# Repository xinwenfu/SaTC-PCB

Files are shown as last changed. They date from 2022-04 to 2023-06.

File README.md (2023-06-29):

# SIC2_EDU

## Version 1
Programming &amp; Hardware guide for SIC2_EDU security IoT kit 

SatC_EDU project is an ESP32 based board designed to communicate with AWS or other data servers, in this case using MQTT more securely. On-board is an ATECC608 Crypto authentication chip that provides a means for IoT to communcate more securely.

SatC_EDU Board in bumper case render ~ (Autodesk, Fusion360)
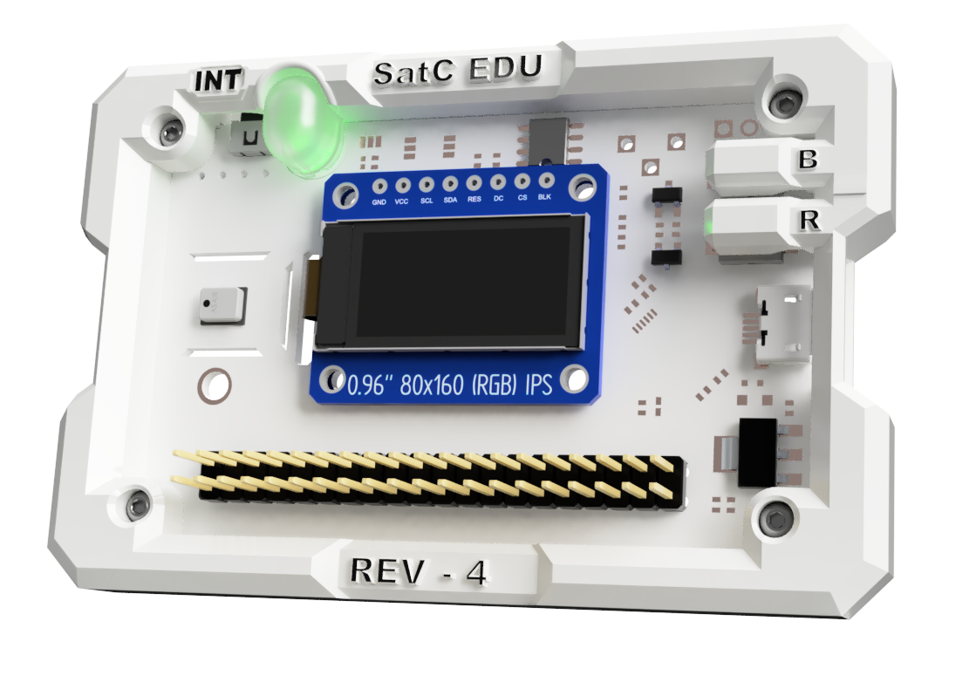
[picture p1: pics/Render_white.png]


Schematic ~ (Based on schems from espressif)
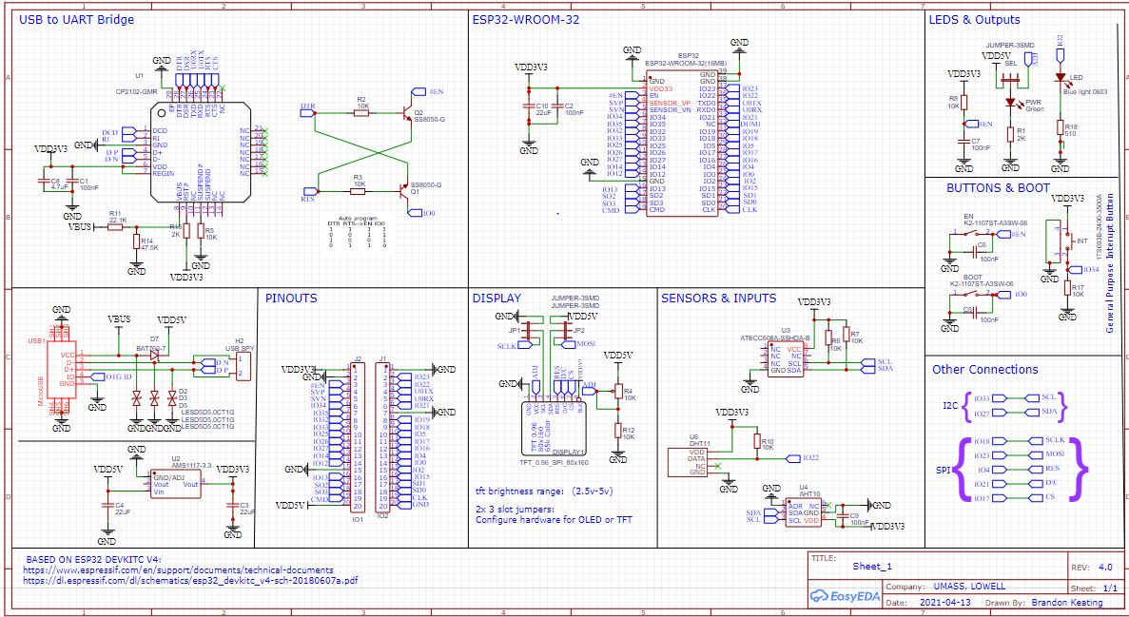
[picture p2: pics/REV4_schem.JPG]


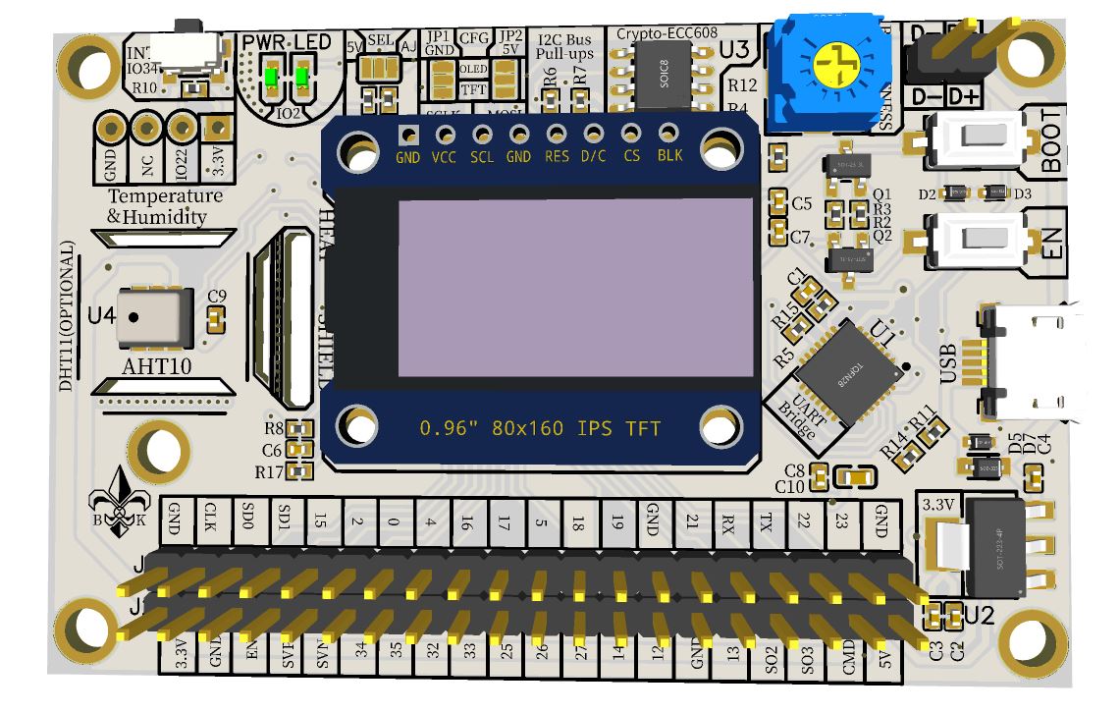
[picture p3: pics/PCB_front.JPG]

Front Face of PCB

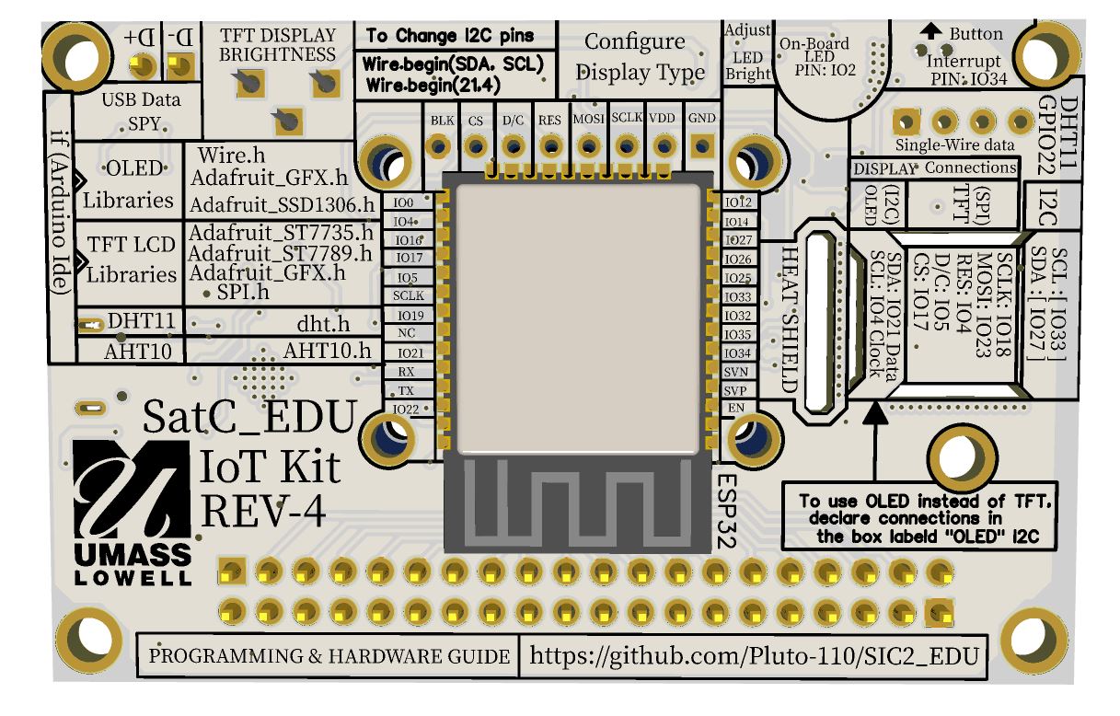
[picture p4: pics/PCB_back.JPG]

Back Face of PCB

## Version 2
Version 2 of the PCB is available at [Amazon](https://www.amazon.com/dp/B0C24FJBG9)
Security chip model: HSC32I1NBV60X2115, compatible with ECC608

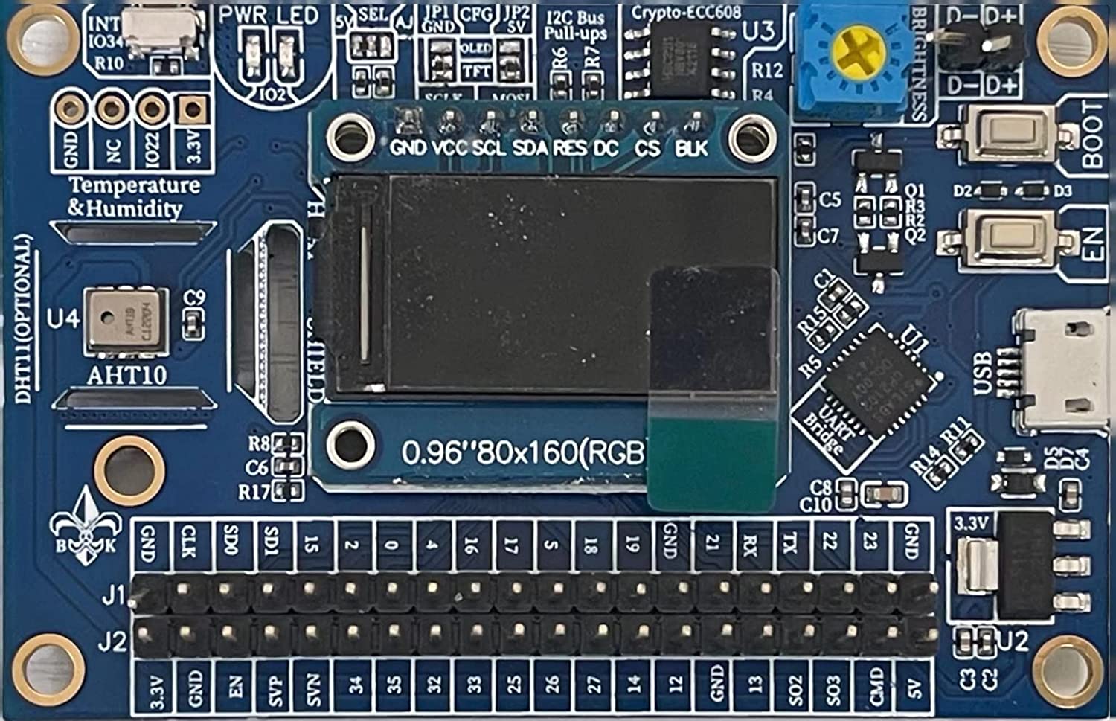
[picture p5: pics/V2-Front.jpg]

Front Face of PCB

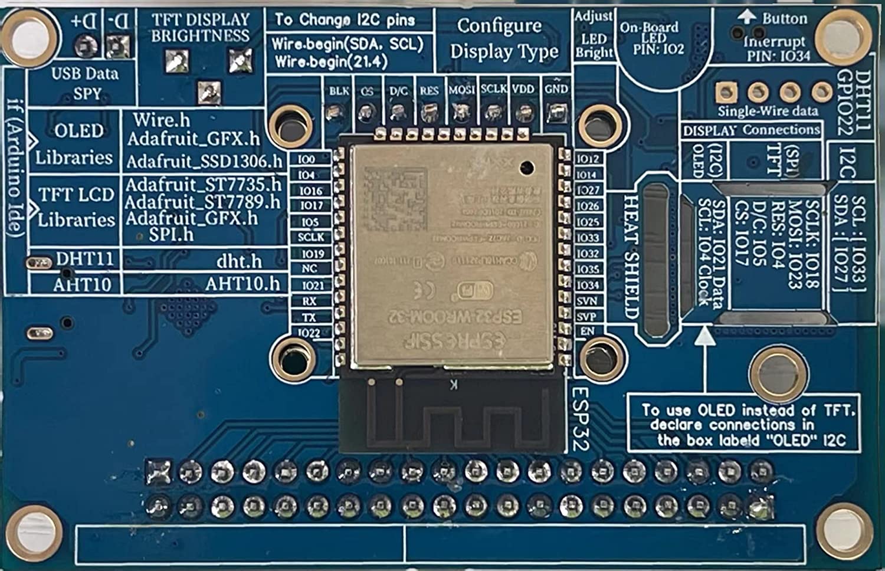
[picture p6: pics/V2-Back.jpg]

Back Face of PCB

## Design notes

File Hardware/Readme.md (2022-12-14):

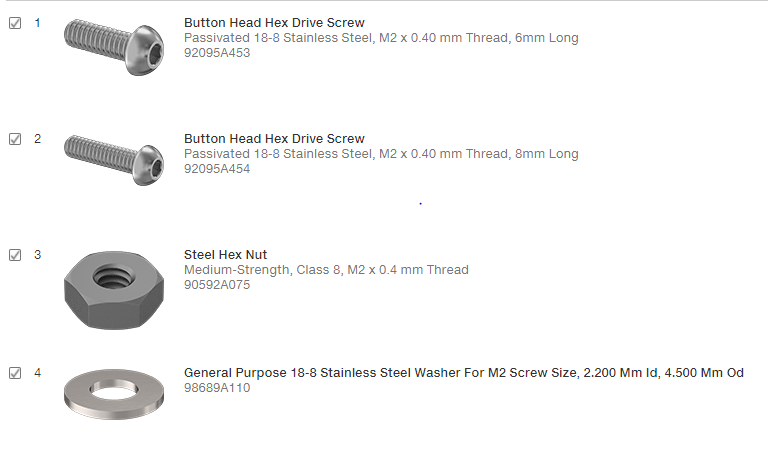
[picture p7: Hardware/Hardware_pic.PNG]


  Per Unit: [Full Hareware]
    4x M2 Hex Drive 8mm Screw (4 corners of the case)
    5x M2 Hex Drive 6mm Screw (1x for DHT22, 4x for TFT screen)
    4x Steel Hex Nut
    12x M2 general purpose washer (Board to TFT screen seperators) 

  Per Unit: [Minimal Hareware]
    2x M2 Hex Drive 8mm Screw (2 opposite corners of the case)
    1x M2 Hex Drive 6mm Screw (1x for DHT22)
    4x Steel Hex Nut

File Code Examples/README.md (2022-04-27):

Our board works with Arduino. Set the board as ESP32 Dev Module.

Our board works with the ESP-IDF extension and PlatformIO extension of VSCode. 

For the PlatformIO extension, use the board Espressif ESP32 Dev Module. In the interface of PIO, we can use "Import Arduino Project" to import an Arduino project. There is no need marking "Use libraries installed by Arduino IDE".

platformio.ini looks like the following
```
; PlatformIO Project Configuration File
;
;   Build options: build flags, source filter
;   Upload options: custom upload port, speed and extra flags
;   Library options: dependencies, extra library storages
;   Advanced options: extra scripting
;
; Please visit documentation for the other options and examples
; https://docs.platformio.org/page/projectconf.html

[env:esp32dev]
platform = espressif32
board = esp32dev
framework = arduino
```

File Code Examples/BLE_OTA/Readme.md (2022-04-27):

This Example shows how  to use BLE to implement OTA for the SIC2_EDU board. This example is an adaptation of an existing guide to do OTA via BLE which can be found here below.

https://learn.sparkfun.com/tutorials/esp32-ota-updates-over-ble-from-a-react-web-application/all#introduction 

This is my board, not my code!! Code credit:  [ ENGLANDSAURUS ]

Tools needed:
  * SatC_EDU IoT Kit
  * A PC running Windows that has Arduino IDE installed (dont forget to add the espressif ESP32 board to the ide!) 
  * A PC running Linux (Ubunut, Arch, etc...), also have nodeJS and npm installed https://linuxize.com/post/how-to-install-node-js-on-ubuntu-20-04/
  * Micro-USB cable with data lines 

Setup:
  *add ESP32 capability to arduino ide : https://randomnerdtutorials.com/installing-the-esp32-board-in-arduino-ide-windows-instructions/
  *Install NPM and NODEJS to linux machine 
  
Step 1: (Arrange Files)
  Download or clone this repo and extract it to a known location. Do this on both the windows machine and the linux machine. 
  
Step 2: (Set up & Flash SatC_EDU)
  *Open arduino ide and open the Arduino sketch titled "BLE_OTA_main" 
  *Select the ESP32 Dev Module under "tools -> Board" in the ide
  *Under "Partitioon Schemes" select "Minimal SPIFFS(1.9MB APP with OTA/190KB SPIFFS", this will configure the partition sizes on the ESP32 to allocate space to store the update.
  
Step 3:
  *In the linux machine, open a command termnial (ctrl + alt + t) 
  *Navigate to where you unzipped the git clone and cd into WebApp
   if using the VM use " cd Desktop/ESP32_OTA_BLE_React_WebApp_Demo-master/WebApp " - NOTE:[ I extracted to the desktop but you can put the file anywhere... ]
  * Run the command "HPPT = true npm start". This will begin the WebApp

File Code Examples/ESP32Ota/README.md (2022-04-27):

This project is from https://github.com/atomic14/ESP32Ota.

# Introduction

This project demonstrates how to use the Arduino Over The Air update system on an ESP32.
Click the image to watch the demo video.

Demo Video (https://www.youtube.com/watch?v=_bMsrxiyuHs)

# Setup

Update the file `wifi_credentials.h` with your SSID and PASSWORD.

```c
#define SSID "YOUR_SSID"
#define PASSWORD "YOUR_PASSWORD"
```

Now just compile and run the sketch.

The first install will need to over USB.

Once the sketch is running you can go to "Tools" -> "Ports" and you should find your ESP32 listed as "esp_test".

You can change the name of your device by changing this line of code:

```c
ArduinoOTA.setHostname("esp_test");
```

# OTA in pio
In pio, we need to specify the upload_protocol and upload_port, which is the ip address of the board. One example platformio.ini looks like the following. This example uses the Arduino library installed by Arduino IDE. But really pay attention to the last two lines.

```
; PlatformIO Project Configuration File
;
;   Build options: build flags, source filter
;   Upload options: custom upload port, speed and extra flags
;   Library options: dependencies, extra library storages
;   Advanced options: extra scripting
;
; Please visit documentation for the other options and examples
; https://docs.platformio.org/page/projectconf.html

[env:esp32dev]
platform = espressif32
board = esp32dev
framework = arduino
lib_extra_dirs = ~/Documents/Arduino/libraries
monitor_speed = 115200

upload_protocol = espota
upload_port = 192.168.1.18
```

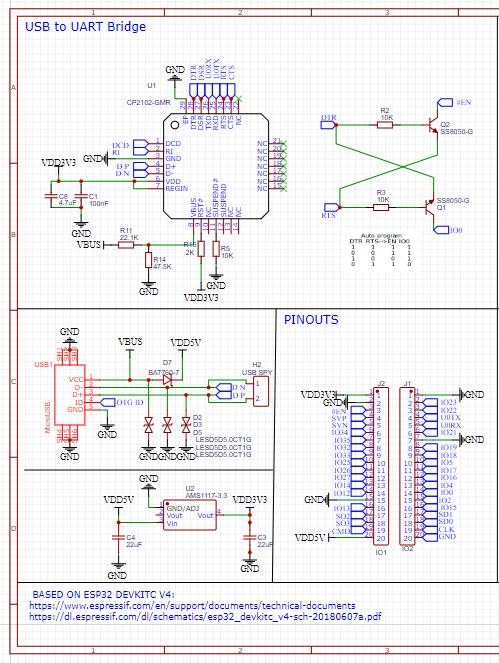
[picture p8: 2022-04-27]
pics/REV4_schem_cp2102.JPG

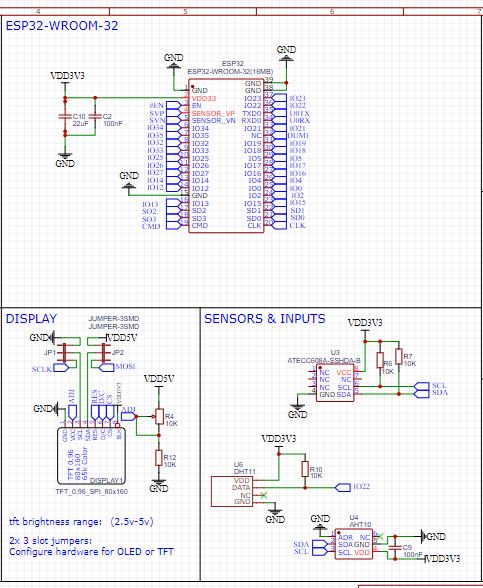
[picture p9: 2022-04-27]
pics/REV4_schem_esp32.JPG

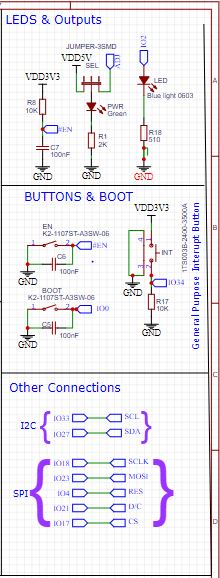
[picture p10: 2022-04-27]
pics/REV4_schem_cont.JPG

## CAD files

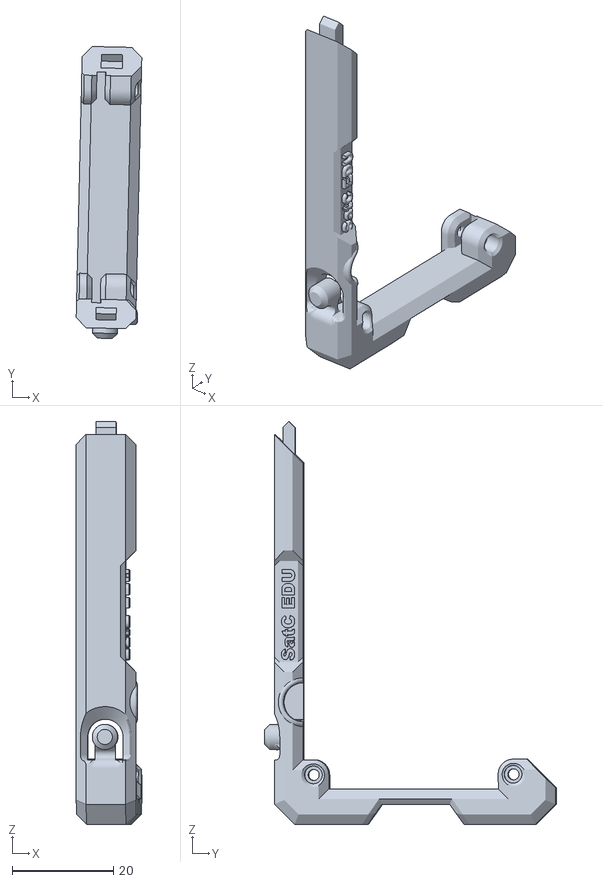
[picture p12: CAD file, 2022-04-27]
Case_stls/SIC2_case_full.stl
13.0 x 57.7 x 79.7

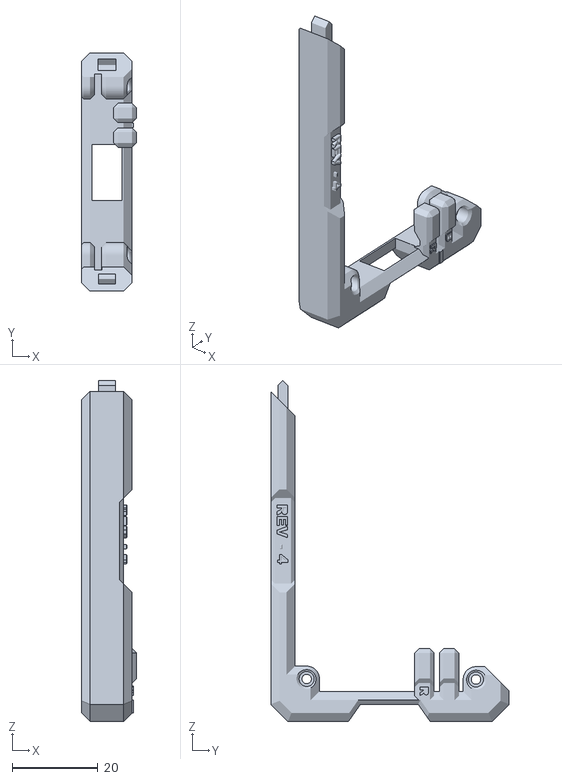
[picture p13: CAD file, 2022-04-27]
Case_stls/SIC2_case_buttons.stl
12.8 x 55.6 x 79.5

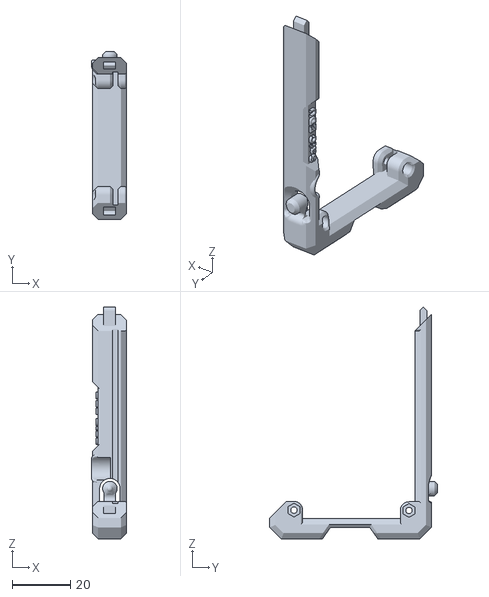
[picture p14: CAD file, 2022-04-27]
Case_stls/SIC2_case_LED_INT.stl
12.1 x 57.6 x 79.7

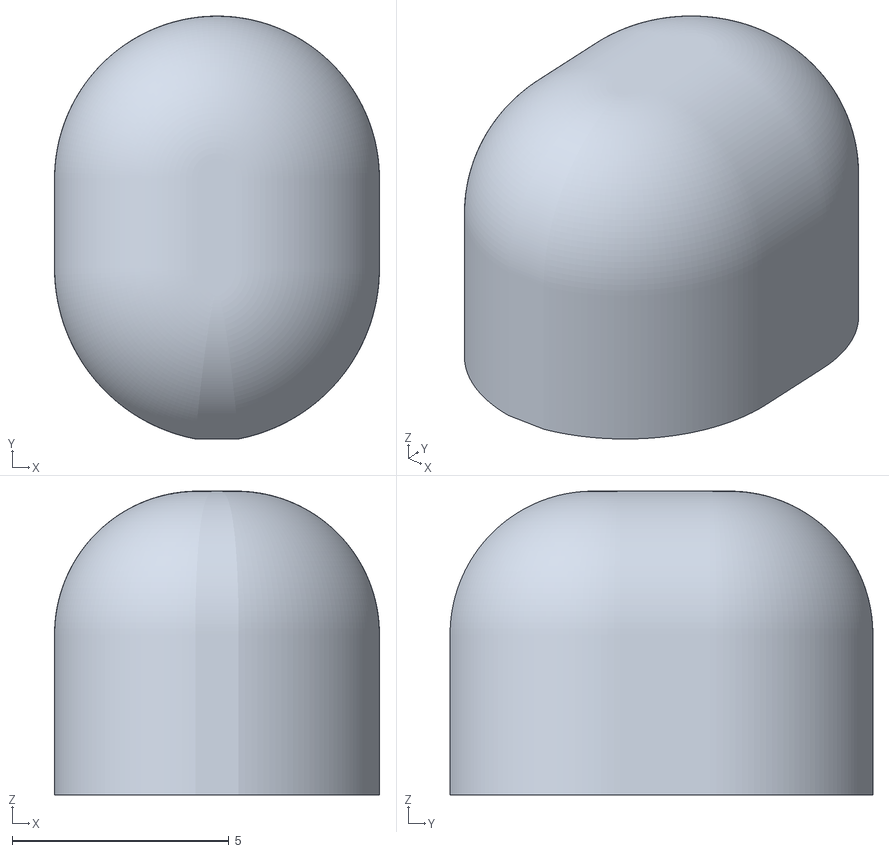
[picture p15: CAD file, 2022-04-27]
Case_stls/SIC2_case_Diffuser.stl
7.49 x 9.74 x 7.00

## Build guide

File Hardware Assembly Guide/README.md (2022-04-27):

# SIC2_EDU
## Assembly guide for SIC2_EDU security IoT kit Printed Circuit Board.

This is a guide on the assembly and soldering of the SatC_EDU IoT kit PCB.

The very first component that should be placed and soldered is the micro-USB connector that allows the board to be connected to a PC for programming and power. 

These connectors have two protrusions on the bottom that fit into the two board cut outs on the USB footprint outline. This makes lining up the small data and power lines very easy. 
 
Add a little bit of flux to the board where the connector will go. Once the connector is placed, turn the board over and sill in the holes that the USB prongs stick through. Fill these holes with solder, this will assure the USB connector does not break off or move around. 

Once in the place the five small pins will sit alligned with the solder pads underneith them. These connections should be soldered with a fine tip, one by one, combing is NOT advised.

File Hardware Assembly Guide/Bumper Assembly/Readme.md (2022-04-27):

Link to assembly video (Watch at 0.5 speed for maximum detail) 

https://www.youtube.com/watch?v=C4VOqvhsHR4

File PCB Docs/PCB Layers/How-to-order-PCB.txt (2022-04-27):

How to Order PCB

Please refer to:
https://docs.easyeda.com/en/PCB/Order-PCB

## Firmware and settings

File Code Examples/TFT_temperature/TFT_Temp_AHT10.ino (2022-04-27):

/**************************************************************************

 **************************************************************************/

#include <Adafruit_GFX.h>    // Core graphics library
#include <Adafruit_ST7735.h> // Hardware-specific library for ST7735
#include <Adafruit_ST7789.h> // Hardware-specific library for ST7789
#include <SPI.h>
#include <Wire.h>
#include "DHT.h"
#include "WiFi.h"
#include "time.h"
#include <AHT10.h>

#define screenWidth 160
#define screenHeight 80 
#define HUD_height 20

#define HUD_color ST77XX_RED
//SPI declarations
  #define TFT_CS         17
  #define TFT_RST        4 
  #define TFT_DC         21
  #define TFT_MOSI       23  // Data out
  #define TFT_SCLK       18  // Clock out

  #define LED            2 // on-board LED
  //  reference for ESP32 SatC_EDU REV-3 board's physical pins connections to VSPI:
  // SDA  GPIO23 aka VSPI MOSI
  // SCLK GPIO18 aka SCK aka VSPI SCK
  // D/C  GPIO15 aka A0 (also I2C SDA)
  // RST  GPIO4 aka RESET (also I2C SCL) 
  // CS   GPIO5  aka chip select
  // LED  3.3V
  // VCC  5V
  // GND - GND


  
  //Temp & Humidity Sensor
  //#define DHTPIN 22     // Digital pin connected to the DHT sensor
 // #define DHTTYPE DHT22   // DHT 22  (AM2302), AM2321

  
// For ST7735-based display
Adafruit_ST7735 tft = Adafruit_ST7735(TFT_CS, TFT_DC, TFT_MOSI, TFT_SCLK, TFT_RST);


 //DHT dht(DHTPIN, DHTTYPE);
uint8_t readStatus = 0;
AHT10 myAHT10(AHT10_ADDRESS_0X38);
float p = 3.1415926;

/*
 * //disconnect WiFi as it's no longer needed
  WiFi.disconnect(true);
  WiFi.mode(WIFI_OFF);
 */


const char* ssid = "SSID";
const char* password =  "password";

const char* ntpServer = "pool.ntp.org";
const long  gmtOffset_sec = -5 *3600;//for timezone
const int   daylightOffset_sec = 3600;

void setup(void) {
  
  int i = 0;
  Wire.begin(27,33);
  Serial.begin(115200);
  Serial.print(F("Hello! ST77xx TFT Test"));
 
  pinMode(LED, OUTPUT);
  digitalWrite(LED, HIGH);
  
  delay(100);
  tft.initR(INITR_MINI160x80);  // Init ST7735S mini display, using a 0.96" 160x80 TFT:
  delay(100);
  tft.setRotation(3);
  //dht.begin();
  uint8_t sda = 27;
  uint8_t  scl = 33;
    tft.fillScreen(ST77XX_BLACK);
    tft.invertDisplay(true);
    tft.setTextColor(ST77XX_GREEN);
    tft.setCursor(20,25);
    tft.print("connecting to sensor...");
    while (myAHT10.begin(sda,scl) != true)
  {
   tft.print("Sensor not found");
    Serial.println(F("AHT10 not connected or fail to load calibration coefficient")); //(F()) save string to flash & keeps dynamic memory free
    delay(5000);
  }
  Serial.println(F("AHT10 OK"));
  Serial.println(F("Initialized"));
  
  uint16_t time = millis();
  tft.fillScreen(ST77XX_BLACK);

  time = millis() - time;
  
  logo(ST77XX_GREEN);
  delay(1500);
  
 // welcome();  // display welcome message
  
  for(; i < 4; i++){
  digitalWrite(LED, HIGH);
  delay(100);
  digitalWrite(LED, LOW);
  delay(100);
  }
  // large block of text
 
  //WELCOME MESSAGE HERE!!!!

    tft.fillScreen(ST77XX_BLACK);
    welcome();
    delay(1000);
    tft.fillScreen(ST77XX_BLACK);
    HUD();
    
   
    delay(500);
    tft.setCursor(screenWidth-3*screenWidth/4+20, HUD_height-8);
    tft.setTextColor(ST77XX_YELLOW);
    tft.print("Connecting");
    for(i=0; i < 4;i++){
      tft.drawChar(screenWidth-3*screenWidth/4+80+i*2, HUD_height-10,'.',ST77XX_YELLOW,1,1);
      //void drawChar(uint16_t x, uint16_t y, char c, uint16_t color, uint16_t bg, uint8_t size);
      delay(250);
    }
    WiFi.begin(ssid, password);
    delay(500);
    tft.fillRect(screenWidth/2-20, HUD_height - 10, 70,10, ST77XX_BLACK);
}

void loop() {
  int j;
  int startY = HUD_height+8;
  int startX = 8;
  int textH = 12;
  digitalWrite(LED, LOW);
 
  /*
  float h = myAHT10.readHumidity();
  // Read temperature as Celsius (the default)
  float t = myAHT10.readTemperature();
  // Read temperature as Fahrenheit (isFahrenheit = true)
  float f = dht.readTemperature(true);

  // Check if any reads failed and exit early (to try again).
  if (isnan(h) || isnan(t) || isnan(f)) {
  tft.fillScreen(ST77XX_BLACK);
  tft.setCursor(30, 30);
  tft.setTextColor(ST77XX_GREEN);
  tft.setTextSize(2);
  tft.println("FAILED TO READ SENSOR..");
 // tft.invertDisplay(true);
  delay(500);
 // tft.invertDisplay(false);
  delay(500);
//  tft.invertDisplay(true);
  delay(500);
 // tft.invertDisplay(false);
  delay(500);
  digitalWrite(LED, LOW);
   
    return;
  }
*/
  // Compute heat index in Fahrenheit (the default)
//  float hif = dht.computeHeatIndex(f, h);
  // Compute heat index in Celsius (isFahreheit = false)
 // float hic = dht.computeHeatIndex(t, h, false);
 
  //tft.setTextWrap(false);
   
 // tft.fillScreen(ST77XX_BLACK);
  //tft.invertDisplay(true);

   tft.fillRect(83, startY, 100, 32, ST77XX_BLACK);
   
   tft.fillRect(80, startY+25, 80, 15, ST77XX_BLACK);
   float tempF = 0;
   float tempC = 0;
   tempC = myAHT10.readTemperature();
   tempF = (tempC*1.8)+32;
  tft.setCursor(startX, startY);
  tft.setTextColor(ST77XX_GREEN);
  tft.setTextSize(1);
  tft.println("Temperature: ");
  tft.setCursor(90, startY);
  tft.setTextColor(ST77XX_GREEN);
  tft.setTextSize(1);
  tft.println(tempC);

  tft.drawCircle(125,startY-1,2,ST77XX_GREEN);
  // tft.drawCircle(x, y, radius, color);
  tft.setCursor(130, startY);
  tft.setTextColor(ST77XX_GREEN);
  tft.setTextSize(1);
  tft.println("C");

 

  tft.setCursor(startX, startY+textH);
  tft.setTextColor(ST77XX_GREEN);
  tft.setTextSize(1);
  tft.println("Temperature: ");
  tft.setCursor(90, startY+textH);
  tft.setTextColor(ST77XX_GREEN);
  tft.setTextSize(1);
  tft.println(tempF);

  tft.drawCircle(125,startY+textH-1,2,ST77XX_GREEN);
  // tft.drawCircle(x, y, radius, color);
  tft.setCursor(130, startY+textH);
  tft.setTextColor(ST77XX_GREEN);
  tft.setTextSize(1);
  tft.println("F");

  
  tft.setCursor(startX, startY+(2*textH));
  tft.setTextColor(ST77XX_GREEN);
  tft.setTextSize(1);
  tft.println("Humidity: ");
 
  //tft.drawRect(x, y, width, height, color);
  tft.setCursor(80, startY+(2*textH));
  tft.setTextColor(ST77XX_GREEN);
  tft.setTextSize(1);
  tft.println(myAHT10.readHumidity());
  tft.setCursor(115, startY+(2*textH));
  tft.setTextColor(ST77XX_GREEN);
  tft.setTextSize(1);
  tft.println("%");

  delay(1000); // wait between measurments 

for(j = 0; j < 100; j++){
  tft.fillRect(60, 65, 90, 75, ST77XX_BLACK);
  
  tft.setCursor(5, 70);
  tft.setTextColor(ST77XX_MAGENTA);
  tft.setTextSize(1);
  tft.println("cooldown:");
  
  tft.setCursor(65, 70);
  tft.setTextColor(ST77XX_YELLOW);
  tft.setTextSize(1);
  tft.println(99-j);
  delay(100);
}
digitalWrite(LED, HIGH);
  /*
  tft.invertDisplay(true);
  delay(500);
  tft.invertDisplay(false);
  delay(500);
  */
  Zeit();
  /*
  if(f > 82)  {
     for(j=0 ; j < 4; j++)  {
          digitalWrite(LED, HIGH);
          delay(100);
          digitalWrite(LED, LOW);
          delay(100);
    }
  }
  else;
  */
}

/**********************************/
void tempMeas(){
  
}

void Zeit(){
 
  configTime(gmtOffset_sec, daylightOffset_sec, ntpServer);
  struct tm timeinfo;
  if(!getLocalTime(&timeinfo)){
    Serial.println("Failed to obtain time");
    return;
  }
  Serial.println("GOT TIME!");
  tft.fillRect(screenWidth/2-10, HUD_height - 12, 38,12, ST77XX_BLACK);
  tft.setTextColor(ST77XX_GREEN);
  tft.setCursor(68, 8);
  tft.setTextSize(1);
  tft.println(&timeinfo, "%H:%M");

  
}


void logo(uint16_t color){
   
//void drawChar(uint16_t x, uint16_t y, char c, uint16_t color, uint16_t bg, uint8_t size);
  tft.drawTriangle(80,10,70,30,80,50, color);
  tft.fillTriangle(80,10,90,30,80,50, color);

  tft.fillTriangle(79,60,75,70,79,80, color);
  tft.drawTriangle(80,60,85,70,80,80, color);
 
  tft.drawCircle(100,45,12, color); //right side
  tft.drawCircle(95,55,9, color);
  tft.drawCircle(65,55,9, color);

  tft.drawChar(40, 60, 'B', color,1,2);
  tft.drawChar(110, 60, 'K', color,1,2);
  tft.drawCircle(60,45,12, color);
  tft.drawCircle(71,65,7, color);
  tft.drawCircle(89,65,7, color);
  tft.fillCircle(95,55,7, ST77XX_BLACK);
  tft.fillCircle(65,55,7, ST77XX_BLACK);
  tft.fillCircle(98,61,4, ST77XX_BLACK);
  tft.fillCircle(62,61,4, ST77XX_BLACK);
  tft.fillCircle(80,55, 4, color);
  // tft.drawCircle(125,14,2,ST77XX_GREEN);
  //tft.drawTriangle(w, y, y, x, z, x, color);
}
void welcome(){
  tft.setCursor(30, 20);
  tft.setTextColor(ST77XX_RED);
  tft.setTextSize(2);
  tft.println("SaTC_EDU");

  tft.setCursor(30, 50);
  tft.setTextColor(ST77XX_CYAN);
  tft.setTextSize(2);
  tft.println("Welcome");
}

void heatGraph(){
  int graphH = 60;
  int graphW = 120;

  
}
void HUD(){
  int lineHeight = 1;
  tft.fillRect(0, 0, 160,HUD_height, ST77XX_BLACK); // black backround 
  tft.setCursor(5,HUD_height-10);
  tft.setTextColor(HUD_color);
  tft.setTextSize(1);
  tft.print("SatC_EDU");
  tft.fillRect(0,HUD_height, screenWidth, 2,HUD_color);

  Wifibars();
}

void Wifibars(){
   WiFi.begin(ssid, password);
   long rssi =-1* WiFi.RSSI();
   int barWidth = 4 ;
   int x = screenWidth - barWidth*6;
   int y = abs(HUD_height-5);

   tft.setCursor(x-35,y+55);
   tft.setTextColor(ST77XX_RED);
   tft.print("RSSI:");
   tft.setCursor(x-5,y+55);
   tft.print(rssi);
   if(rssi <= 55){
       tft.fillRect(x, y, 3, -4,  ST77XX_WHITE);
       tft.fillRect(x+barWidth, y, 3, -6, ST77XX_WHITE);
       tft.fillRect(x+2*barWidth, y, 3, -8, ST77XX_WHITE);
       tft.fillRect(x+3*barWidth, y, 3, -10, ST77XX_WHITE);
   }
   else if(rssi <= 100){
       tft.fillRect(x, y, 3, -4,  ST77XX_RED);
       tft.fillRect(x+barWidth, y, 3, -6, ST77XX_WHITE);
       tft.fillRect(x+2*barWidth, y, 3, -8, ST77XX_WHITE);
       tft.fillRect(x+3*barWidth, y, 3, -10, ST77XX_WHITE);
   }
   else if(rssi <= 175){
        tft.fillRect(x, y, 3, -4,  ST77XX_RED);
       tft.fillRect(x+barWidth, y, 3, -6, ST77XX_RED);
       tft.fillRect(x+2*barWidth, y, 3, -8, ST77XX_WHITE);
       tft.fillRect(x+3*barWidth, y, 3, -10, ST77XX_WHITE);
   }
   else if(rssi <= 255){
        tft.fillRect(x, y, 3, -4,  ST77XX_RED);
       tft.fillRect(x+barWidth, y, 3, -6, ST77XX_RED);
       tft.fillRect(x+2*barWidth, y, 3, -8, ST77XX_RED);
       tft.fillRect(x+3*barWidth, y, 3, -10, ST77XX_WHITE);
   }
   else if(rssi < 55){
       tft.fillRect(x, y, 3, -4,  ST77XX_RED);
       tft.fillRect(x+barWidth, y, 3, -6, ST77XX_RED);
       tft.fillRect(x+2*barWidth, y, 3, -8, ST77XX_RED);
       tft.fillRect(x+3*barWidth, y, 3, -10, ST77XX_RED);
   }
   else;
  // tft.setCursor(20,20);
  // tft.print(rssi);
  WiFi.disconnect(true);
}

void testlines(uint16_t color) {
  tft.fillScreen(ST77XX_BLACK);
  for (int16_t x=0; x < tft.width(); x+=6) {
    tft.drawLine(0, 0, x, tft.height()-1, color);
    delay(0);
  }
  for (int16_t y=0; y < tft.height(); y+=6) {
    tft.drawLine(0, 0, tft.width()-1, y, color);
    delay(0);
  }

  tft.fillScreen(ST77XX_BLACK);
  for (int16_t x=0; x < tft.width(); x+=6) {
    tft.drawLine(tft.width()-1, 0, x, tft.height()-1, color);
    delay(0);
  }
  for (int16_t y=0; y < tft.height(); y+=6) {
    tft.drawLine(tft.width()-1, 0, 0, y, color);
    delay(0);
  }

  tft.fillScreen(ST77XX_BLACK);
  for (int16_t x=0; x < tft.width(); x+=6) {
    tft.drawLine(0, tft.height()-1, x, 0, color);
    delay(0);
  }
  for (int16_t y=0; y < tft.height(); y+=6) {
    tft.drawLine(0, tft.height()-1, tft.width()-1, y, color);
    delay(0);
  }

  tft.fillScreen(ST77XX_BLACK);
  for (int16_t x=0; x < tft.width(); x+=6) {
    tft.drawLine(tft.width()-1, tft.height()-1, x, 0, color);
    delay(0);
  }
  for (int16_t y=0; y < tft.height(); y+=6) {
    tft.drawLine(tft.width()-1, tft.height()-1, 0, y, color);
    delay(0);
  }
}

void testdrawtext(char *text, uint16_t color) {
  tft.setCursor(0, 0);
  tft.setTextColor(color);
  tft.setTextWrap(true);
  tft.print(text);
}

void testfastlines(uint16_t color1, uint16_t color2) {
  tft.fillScreen(ST77XX_BLACK);
  for (int16_t y=0; y < tft.height(); y+=5) {
    tft.drawFastHLine(0, y, tft.width(), color1);
  }
  for (int16_t x=0; x < tft.width(); x+=5) {
    tft.drawFastVLine(x, 0, tft.height(), color2);
  }
}


void testfillcircles(uint8_t radius, uint16_t color) {
  for (int16_t x=radius; x < tft.width(); x+=radius*2) {
    for (int16_t y=radius; y < tft.height(); y+=radius*2) {
      tft.fillCircle(x, y, radius, color);
    }
  }
}

void testdrawcircles(uint8_t radius, uint16_t color) {
  for (int16_t x=0; x < tft.width()+radius; x+=radius*2) {
    for (int16_t y=0; y < tft.height()+radius; y+=radius*2) {
      tft.drawCircle(x, y, radius, color);
    }
  }
}

void testtriangles() {
  tft.fillScreen(ST77XX_BLACK);
  int color = 0xF800;
  int t;
  int w = tft.width()/2;
  int x = tft.height()-1;
  int y = 0;
  int z = tft.width();
  for(t = 0 ; t <= 15; t++) {
    tft.drawTriangle(w, y, y, x, z, x, color);
    x-=4;
    y+=4;
    z-=4;
    color+=100;
  }
}

void testroundrects() {
  tft.fillScreen(ST77XX_BLACK);
  int color = 100;
  int i;
  int t;
  for(t = 0 ; t <= 4; t+=1) {
    int x = 0;
    int y = 0;
    int w = tft.width()-2;
    int h = tft.height()-2;
    for(i = 0 ; i <= 16; i+=1) {
      tft.drawRoundRect(x, y, w, h, 5, color);
      x+=2;
      y+=3;
      w-=4;
      h-=6;
      color+=1100;
    }
    color+=100;
  }
}

void tftPrintTest() {
  tft.setTextWrap(false);
  tft.fillScreen(ST77XX_BLACK);
  tft.setCursor(0, 30);
  tft.setTextColor(ST77XX_RED);
  tft.setTextSize(1);
  tft.println("Hello World!");
  tft.setTextColor(ST77XX_YELLOW);
  tft.setTextSize(2);
  tft.println("Hello World!");
  tft.setTextColor(ST77XX_GREEN);
  tft.setTextSize(3);
  tft.println("Hello World!");
  tft.setTextColor(ST77XX_BLUE);
  tft.setTextSize(4);
  tft.print(1234.567);
  delay(1500);
  tft.setCursor(0, 0);
  tft.fillScreen(ST77XX_BLACK);
  tft.setTextColor(ST77XX_WHITE);
  tft.setTextSize(0);
  tft.println("Hello World!");
  tft.setTextSize(1);
  tft.setTextColor(ST77XX_GREEN);
  tft.print(p, 6);
  tft.println(" Want pi?");
  tft.println(" ");
  tft.print(8675309, HEX); // print 8,675,309 out in HEX!
  tft.println(" Print HEX!");
  tft.println(" ");
  tft.setTextColor(ST77XX_WHITE);
  tft.println("Sketch has been");
  tft.println("running for: ");
  tft.setTextColor(ST77XX_MAGENTA);
  tft.print(millis() / 1000);
  tft.setTextColor(ST77XX_WHITE);
  tft.print(" seconds.");
}

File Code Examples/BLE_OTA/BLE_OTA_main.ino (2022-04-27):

#include "BLE.h"
#include "soc/timer_group_struct.h"
#include "soc/timer_group_reg.h"
/**Bluetooth**/
BLE BT;

void setup(void) {
  Serial.begin(115200);
  Serial.println("Serial Begin");
  Serial.println();
  
  Serial.print("HW v");
  Serial.print(HARDWARE_VERSION_MAJOR);
  Serial.print(".");
  Serial.println(HARDWARE_VERSION_MINOR);
  
  Serial.print("SW v");
  Serial.print(SOFTWARE_VERSION_MAJOR);
  Serial.print(".");
  Serial.print(SOFTWARE_VERSION_MINOR);
  Serial.print(".");
  Serial.println(SOFTWARE_VERSION_PATCH);
  
  BT.begin("ESP32 OTA Updates");
}

void loop(void) {
  TIMERG0.wdt_wprotect=TIMG_WDT_WKEY_VALUE;
  TIMERG0.wdt_feed=1;
  TIMERG0.wdt_wprotect=0;
}
